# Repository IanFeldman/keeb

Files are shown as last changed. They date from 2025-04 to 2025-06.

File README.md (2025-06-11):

# A minimal ergo keyboard
Low profile, split, ortholinear, 34-key layout staggered to my natural finger rest positions. Designed for Gateron KS-33 Red swiches and DSA keycaps.
See write-up [here](https://ianfeldman.dev/projects/keyboard/).
<br><br>

Keyboard

## Features
- N-key rollover
- Efficient matrixless polling
- Lightweight and portable
- Serial communication between splits
- USB-C host connection

## Hardware Build Instructions
- Order and assemble PCB's
  - Reflow recommended for all surface mount components except SPI headers, TRRS jack, and crystal oscillator.
  - On hardware version 1.1, there are duplicate C2 and C3 traces. Only solder one C2 and one C3.
- Configure programming setup using In-system programmer (ensure shared ground)
- Power on PCB through USB-C connector
<br><br> _Note: only one PCB can be flashed at a time_

## Software Build and Flash Instructions (Linux)
```sh
# Install dependencies
sudo apt install gcc-avr avr-libc avrdude make

# Clone this repo
git clone https://github.com/IanFeldman/keeb.git
cd keeb

# Compile left or right half
make [left] [right]

# Update makefile targets 'fuses' and 'flash' as needed for your ISP device
# Set fuses with ISP (first time only)
make fuses

# Flash keyboard with ISP
make flash
```

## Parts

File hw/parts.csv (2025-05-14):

Identifier | Digikey Part Number | Unit Quantity | Total Quantity | Description
U1 | ATMEGA16U2-AU-ND | 1 | 2 | mcu
Y1 | XC1282CT-ND | 1 | 2 | 16Mhz crystal
J1 | 2073-USB4105-GF-ACT-ND | 1 | 2 | usbc connector
J2 | CP-SJ2-3574A-SMT-CT-ND | 1 | 2 | trrs connector
J3 | WM20565CT-ND | 1 | 2 | pins
SW1 | CKN12221-1-ND | 1 | 2 | push button
D1, D2, D3, D4 | 475-LSR976-NR-1CT-ND | 4 | 8 | leds
R1, R6, R7, R8, R9, R10 | RMCF0805FT10K0CT-ND | 6 | 12 | 10kohm
R2, R3 | RMCF0805JT22R0CT-ND | 2 | 4 | 22ohm
R4, R5 | RMCF0805JT5K10CT-ND | 2 | 4 | 5.1kohm
C1, C4, C5 | 311-1365-1-ND | 3 | 6 | 1uf
C2, C3 | 311-3614-1-ND | 2 | 4 | 20pf

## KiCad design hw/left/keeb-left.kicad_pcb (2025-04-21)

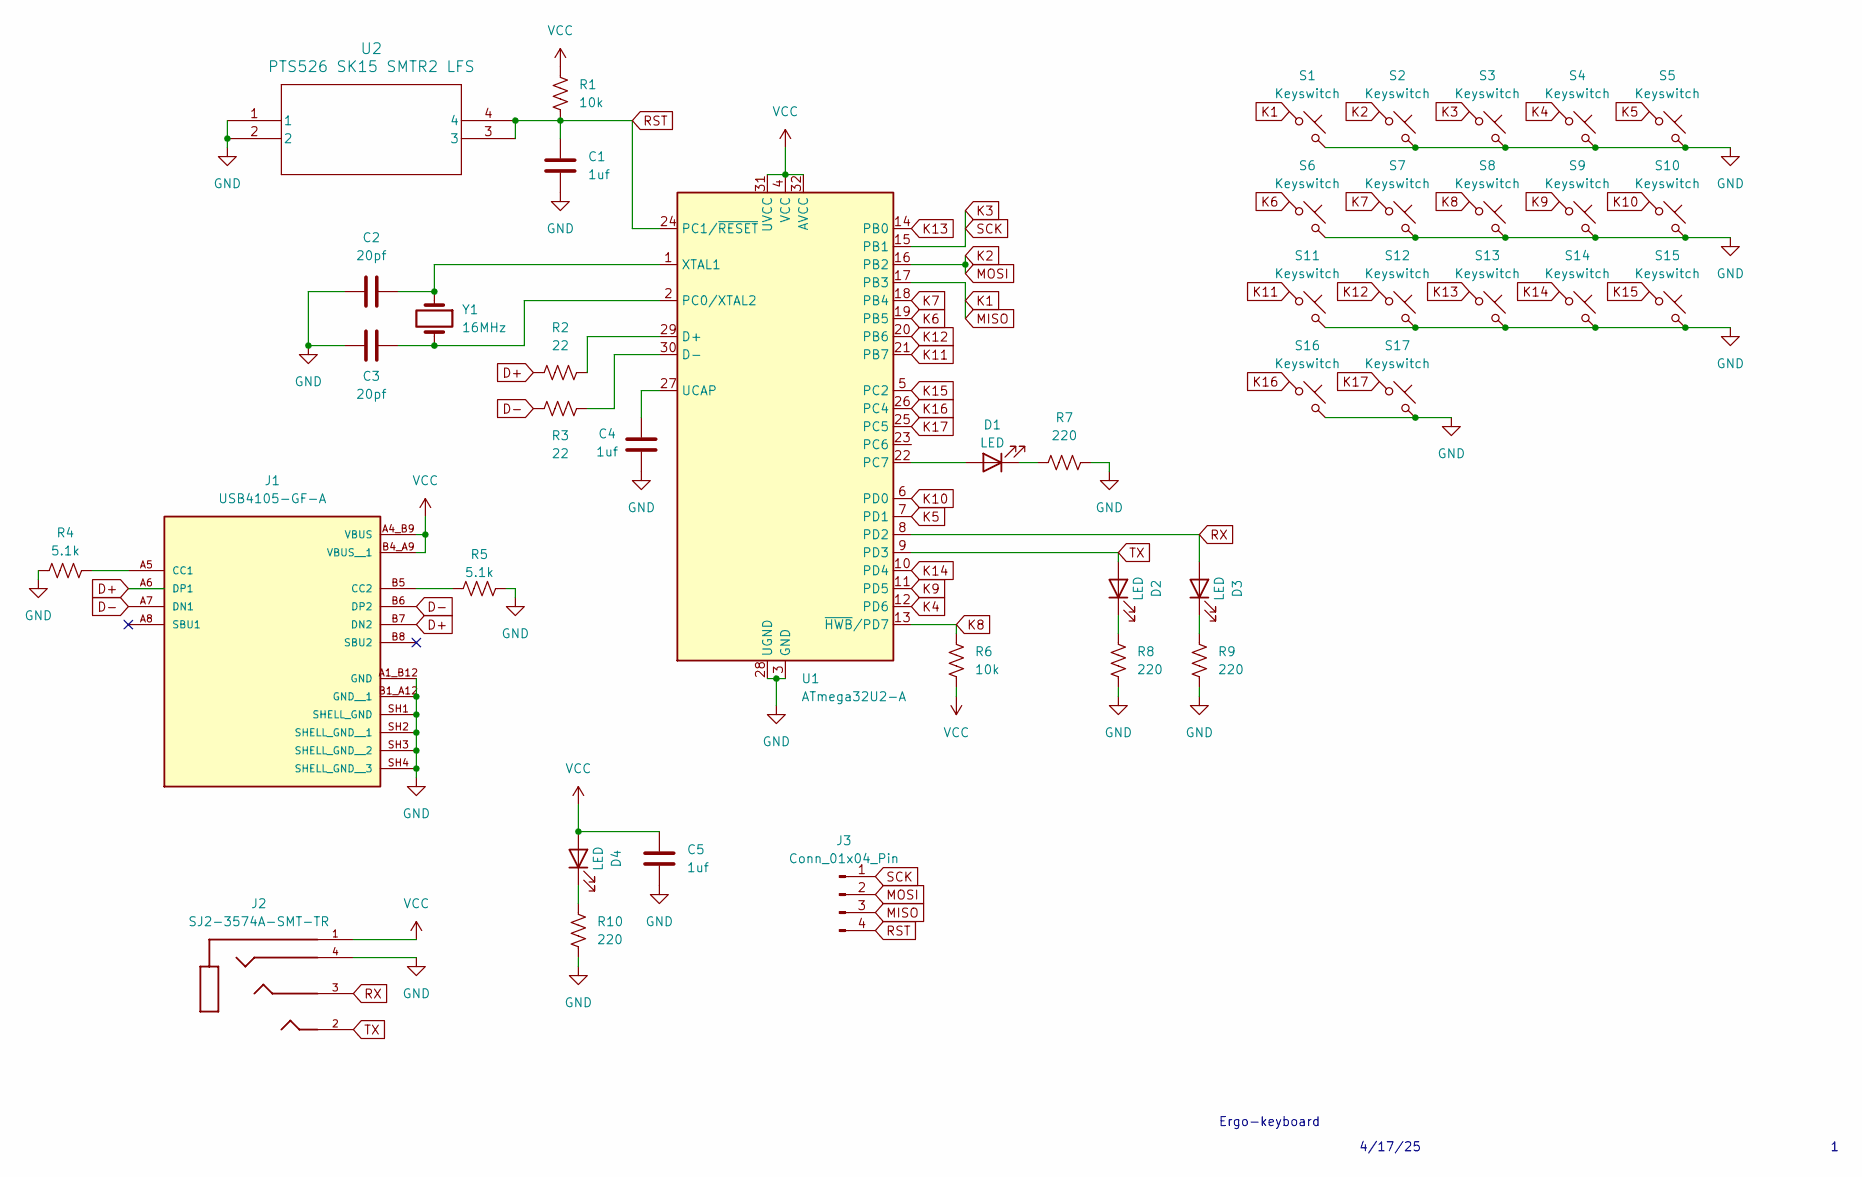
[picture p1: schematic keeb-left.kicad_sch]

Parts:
C1, C4, C5: 1uf; C_0805_2012Metric
C2, C3: 20pf; C_0805_2012Metric
D1, D2, D3, D4: LED; LED_0805_2012Metric
J1: USB4105-GF-A; GCT_USB4105-GF-A; PARTREV B4
J2: SJ2-3574A-SMT-TR; SAMESKY_SJ2-3574A-SMT-TR; PARTREV 1.05
J3: Conn_01x04_Pin; PinSocket_1x04_P2.54mm_Vertical_SMD_Pin1Right
R1, R6: 10k; R_0805_2012Metric
R2, R3: 22; R_0805_2012Metric
R4, R5: 5.1k; R_0805_2012Metric
R7, R8, R9, R10: 220; R_0805_2012Metric
S1, S2, S3, S4, S5, S6, S7, S8, S9, S10, S11, S12, S13, S14, S15, S16, S17: Keyswitch; SW_Gateron_LowProfile_THT_New
U1: ATmega32U2-A; TQFP-32_7x7mm_P0.8mm
U2: PTS526 SK15 SMTR2 LFS; SMT_FS
Y1: 16MHz; XTAL_ECS-160-20-5PX-TR

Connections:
D+: J1.A6 (DP1), J1.B7 (DN2), R2.1
D-: J1.A7 (DN1), J1.B6 (DP2), R3.1
GND: C1.2, C2.1, C3.2, C4.1, C5.1, J1.A1_B12 (GND), J1.B1_A12 (GND__1), J1.SH1 (SHELL_GND), J1.SH2 (SHELL_GND__1), J1.SH3 (SHELL_GND__2), J1.SH4 (SHELL_GND__3), J2.4, R4.1, R5.2, R7.1, R8.1, R9.1, R10.1, S1.2, S2.2, S3.2, S4.2, S5.2, S6.2, S7.2, S8.2, S9.2, S10.2, S11.2, S12.2, S13.2, S14.2, S15.2, S16.2, S17.2, U1.3 (GND), U1.28 (UGND), U2.1, U2.2
K1: J3.3, S1.1, U1.17 (PB3)
K2: J3.2, S2.1, U1.16 (PB2)
K3: J3.1, S3.1, U1.15 (PB1)
K4: S4.1, U1.12 (PD6)
K5: S5.1, U1.7 (PD1)
K6: S6.1, U1.19 (PB5)
K7: S7.1, U1.18 (PB4)
K8: R6.2, S8.1, U1.13 (~HWB/PD7)
K9: S9.1, U1.11 (PD5)
K10: S10.1, U1.6 (PD0)
K11: S11.1, U1.21 (PB7)
K12: S12.1, U1.20 (PB6)
K13: S13.1, U1.14 (PB0)
K14: S14.1, U1.10 (PD4)
K15: S15.1, U1.5 (PC2)
K16: S16.1, U1.26 (PC4)
K17: S17.1, U1.25 (PC5)
unnamed: D1.2 (A), U1.22 (PC7)
unnamed: D1.1 (K), R7.2
unnamed: D2.1 (K), R8.2
unnamed: D3.1 (K), R9.2
unnamed: D4.1 (K), R10.2
unnamed: J1.A5 (CC1), R4.2
unnamed: J1.B5 (CC2), R5.1
unnamed: R2.2, U1.29 (D+)
unnamed: R3.2, U1.30 (D-)
unnamed: C3.1, U1.2 (PC0/XTAL2), Y1.2
unnamed: C4.2, U1.27 (UCAP)
unnamed: C2.2, U1.1 (XTAL1), Y1.1
RST: C1.1, J3.4, R1.2, U1.24 (PC1/~RESET), U2.3, U2.4
RX: D3.2 (A), J2.3, U1.8 (PD2)
TX: D2.2 (A), J2.2, U1.9 (PD3)
VCC: C5.2, D4.2 (A), J1.A4_B9 (VBUS), J1.B4_A9 (VBUS__1), J2.1, R1.1, R6.1, U1.4 (VCC), U1.31 (UVCC), U1.32 (AVCC)

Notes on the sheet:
Ergo-keyboard
4/17/25

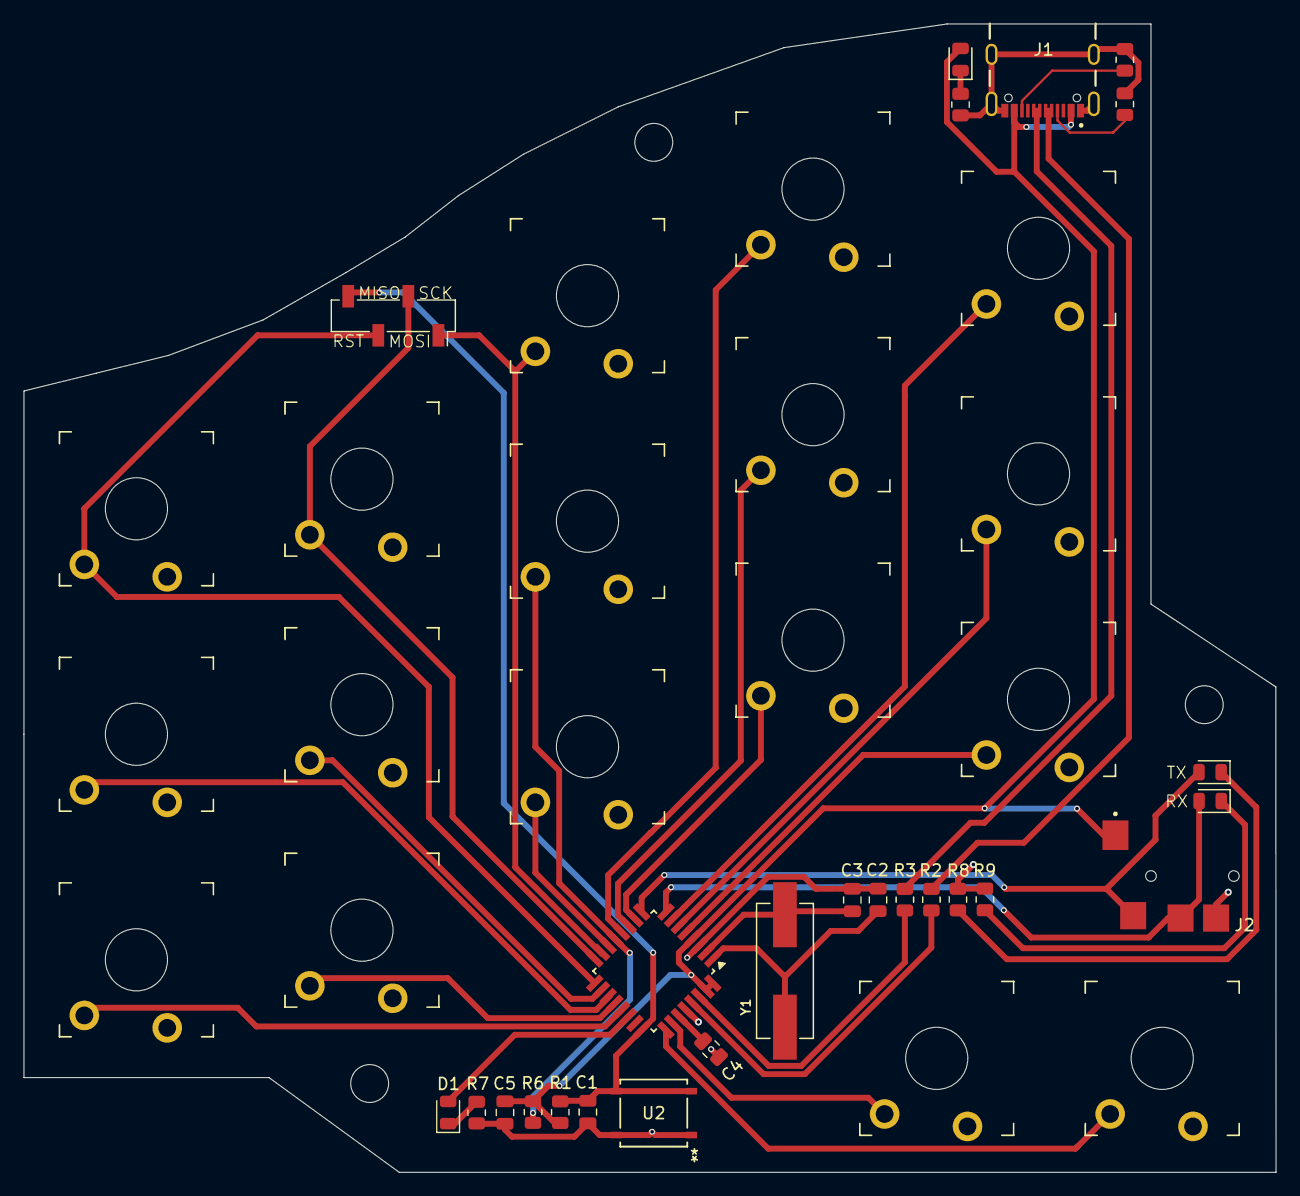
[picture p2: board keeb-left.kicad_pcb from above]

Board: 2 copper layers, 105.8 x 97.0 mm, 42 parts (0 on the bottom side), 36 nets.

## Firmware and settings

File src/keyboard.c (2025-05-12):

/*
             LUFA Library
     Copyright (C) Dean Camera, 2021.

  dean [at] fourwalledcubicle [dot] com
           www.lufa-lib.org
*/

/*
  Copyright 2021  Dean Camera (dean [at] fourwalledcubicle [dot] com)

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
  The author disclaims all warranties with regard to this
  software, including all implied warranties of merchantability
  and fitness.  In no event shall the author be liable for any
  special, indirect or consequential damages or any damages
  whatsoever resulting from loss of use, data or profits, whether
  in an action of contract, negligence or other tortious action,
  arising out of or in connection with the use or performance of
  this software.
*/

/*
 * Edited by Ian Feldman
 * April 2025
 */

#include <stdint.h>
#include "device.h"
#include "keyboard.h"
#include "nkrohid.h"
#include "uart.h"

/* report buffer to store incoming keys from peripheral */
volatile USB_NKRO_Report_Data_t report_buffer_g = {0};
/* keep track if this is main or peripheral */
volatile int main_unit_g = 0;
/* peripheral log if layer key pressed by main */
volatile int layer_key_press_g = 0;

/** Buffer to hold the previously generated Keyboard HID report, for comparison purposes inside the HID class driver. */
static uint8_t PrevKeyboardHIDReportBuffer[sizeof(USB_NKRO_Report_Data_t)];

/** LUFA HID Class driver interface configuration and state information. This structure is
 *  passed to all HID Class driver functions, so that multiple instances of the same class
 *  within a device can be differentiated from one another.
 */
USB_ClassInfo_HID_Device_t Keyboard_HID_Interface =
{
    .Config =
    {
        .InterfaceNumber = INTERFACE_ID_Keyboard,
        .ReportINEndpoint =
        {
            .Address = KEYBOARD_EPADDR,
            .Size = KEYBOARD_EPSIZE,
            .Banks = 1,
        },
        .PrevReportINBuffer = PrevKeyboardHIDReportBuffer,
        .PrevReportINBufferSize = sizeof(PrevKeyboardHIDReportBuffer),
    },
};


/** Main program entry point. This routine contains the overall program flow, including initial
 *  setup of all components and the main program loop.
 */
int main(void)
{
    SetupHardware();

    GlobalInterruptEnable();

    for (;;)
    {
        PeripheralTask();
        HID_Device_USBTask(&Keyboard_HID_Interface);
        USB_USBTask();
    }
}

/** Configures the board hardware and chip peripherals for the demo's functionality. */
void SetupHardware()
{
    /* Disable watchdog if enabled by bootloader/fuses */
    MCUSR &= ~(1 << WDRF);
    wdt_disable();

    /* Disable clock division */
    clock_prescale_set(clock_div_1);

    /* Hardware initialization */
    device_init();
    uart_init();
    USB_Init();
}

/** Peripheral main loop */
void PeripheralTask()
{
    /* skip if not peripheral */
    if (main_unit_g) return;

    /* create usb report */
    USB_NKRO_Report_Data_t KeyboardReport = {0};

    /* poll keys */
    uint8_t input = device_poll(&KeyboardReport, layer_key_press_g);

    /* send keypresses */
    if (input)
    {
        uart_send_report(&KeyboardReport);
    }
}

/** Event handler for the library USB Connection event. */
void EVENT_USB_Device_Connect(void)
{
    main_unit_g = 1;
    device_blink(2);
}

/** Event handler for the library USB Disconnection event. */
void EVENT_USB_Device_Disconnect(void)
{
    main_unit_g = 0;
    device_blink(3);
}

/** Event handler for the library USB Configuration Changed event. */
void EVENT_USB_Device_ConfigurationChanged(void)
{
    bool ConfigSuccess = true;

    ConfigSuccess &= HID_Device_ConfigureEndpoints(&Keyboard_HID_Interface);

    USB_Device_EnableSOFEvents();
}

/** Event handler for the library USB Control Request reception event. */
void EVENT_USB_Device_ControlRequest(void)
{
    HID_Device_ProcessControlRequest(&Keyboard_HID_Interface);
}

/** Event handler for the USB device Start Of Frame event. */
void EVENT_USB_Device_StartOfFrame(void)
{
    HID_Device_MillisecondElapsed(&Keyboard_HID_Interface);
}

/** HID class driver callback function for the creation of HID reports to the host.
 *
 *  \param[in]     HIDInterfaceInfo  Pointer to the HID class interface configuration structure being referenced
 *  \param[in,out] ReportID    Report ID requested by the host if non-zero, otherwise callback should set to the generated report ID
 *  \param[in]     ReportType  Type of the report to create, either HID_REPORT_ITEM_In or HID_REPORT_ITEM_Feature
 *  \param[out]    ReportData  Pointer to a buffer where the created report should be stored
 *  \param[out]    ReportSize  Number of bytes written in the report (or zero if no report is to be sent)
 *
 *  \return Boolean \c true to force the sending of the report, \c false to let the library determine if it needs to be sent
 */
bool CALLBACK_HID_Device_CreateHIDReport(USB_ClassInfo_HID_Device_t* const HIDInterfaceInfo,
    uint8_t* const ReportID,
    const uint8_t ReportType,
    void* ReportData,
    uint16_t* const ReportSize)
{
    /* skip if peripheral */
    if (!main_unit_g) return false;

    /* create usb report */
    USB_NKRO_Report_Data_t* KeyboardReport = (USB_NKRO_Report_Data_t*)ReportData;

    /* poll keys */
    /* get buffered keys first because it might contain layer info */
    memcpy(KeyboardReport, (uint8_t *)&report_buffer_g, sizeof(USB_NKRO_Report_Data_t));
    /* clear buffer */
    memset((uint8_t *)&report_buffer_g, 0x00, sizeof(USB_NKRO_Report_Data_t));

    /* poll main device */
    device_poll(KeyboardReport, layer_key_press_g);
    layer_key_press_g = 0;

    /* send layer key */
    uart_send_layer_info(KeyboardReport);

    /* subtract one for layer byte */
    *ReportSize = sizeof(USB_NKRO_Report_Data_t) - 1;
    return false;
}

/** HID class driver callback function for the processing of HID reports from the host.
 *
 *  \param[in] HIDInterfaceInfo  Pointer to the HID class interface configuration structure being referenced
 *  \param[in] ReportID    Report ID of the received report from the host
 *  \param[in] ReportType  The type of report that the host has sent, either HID_REPORT_ITEM_Out or HID_REPORT_ITEM_Feature
 *  \param[in] ReportData  Pointer to a buffer where the received report has been stored
 *  \param[in] ReportSize  Size in bytes of the received HID report
 */
void CALLBACK_HID_Device_ProcessHIDReport(USB_ClassInfo_HID_Device_t* const HIDInterfaceInfo,
    const uint8_t ReportID,
    const uint8_t ReportType,
    const void* ReportData,
    const uint16_t ReportSize)
{
    /* skip if peripheral */
    if (!main_unit_g) return;
}

/* Main unit receive key state and save to global report buffer
 * Peripheral receive single byte indicating layer key press */
ISR(USART1_RX_vect)
{
    static interrupt_st state = AWAIT_REPORT;
    static int key_idx = 0;

    /* get data */
    uint8_t data = UDR1;

    /* if peripheral, first rx indicates layer key status */
    if (!main_unit_g)
    {
        layer_key_press_g = !!data;
        return;
    }

    /* if main */
    switch(state)
    {
        case AWAIT_REPORT:
            if (data == FRAME_START)
            {
                state = READ_MODIFIER;
            }
            break;
        case READ_MODIFIER:
            report_buffer_g.Modifier |= data;
            state = READ_KEYS;
            break;
        case READ_KEYS:
            report_buffer_g.Keys[key_idx++] |= data;
            if (key_idx >= KEY_BUFFER_SIZE)
            {
                state = READ_LAYER;
                key_idx = 0;
            }
            break;
        case READ_LAYER:
            layer_key_press_g = !!data;
            state = AWAIT_REPORT;
            break;
        default:
            break;
    }
}

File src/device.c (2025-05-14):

#include <avr/io.h>
#include <LUFA/Drivers/USB/USB.h>
#include <util/delay.h>
#include "device.h"
#include "nkrohid.h"

/* Initialize device hardware */
void device_init(void)
{
    /* insert delay to avoid pull up contention  */
    _delay_ms(500);

    /* configure ports as inputs */
    DDRB = 0x00;
    DDRC = 0x00;
    DDRD = 0x00;

    /* enable pull up resistors */
    PORTB = 0xFF;
    PORTC = 0xFF;
    PORTD = 0xFF;

    /* debug led */
    DDRC |= (1 << DEBUG_LED);
    PORTC &= ~(1 << DEBUG_LED);
}


/* Blink debug led */
void device_blink(int count)
{
    for (int i = 0; i < count; i++)
    {
        PORTC ^= (1 << DEBUG_LED);
        _delay_ms(50);
        PORTC ^= (1 << DEBUG_LED);
        _delay_ms(50);
    }
}


/* Enable debug led */
void device_enable_led(int on)
{
    PORTC = on ? (PORTC | (1 << DEBUG_LED)) : (PORTC & ~(1 << DEBUG_LED));
}


/* Poll for keypresses, save to key report.
 * Extern_layer_key is input high when the other unit's layer key is pressed.
 * Return a value if any keys are pressed, 0 otherwise. */
uint8_t device_poll(USB_NKRO_Report_Data_t *report, uint8_t extern_layer_key)
{
    /* used for edge case when layer key lifted and keys still depressed */
    static uint8_t layer_hold = 0;
    static uint8_t prev_layer = 0;
    static uint8_t prev_port_b = 0;
    static uint8_t prev_port_c = 0;
    static uint8_t prev_port_d = 0;

    /* read ports */
    uint8_t port_b = PINB;
    uint8_t port_c = PINC | ~PORTC_INPUT;
    uint8_t port_d = PIND | ~PORTD_INPUT;
    uint8_t input = ~(port_b & port_c & port_d);
    uint8_t input_static = (port_b == prev_port_b) &&
                           (port_c == prev_port_c) &&
                           (port_d == prev_port_d);
    uint8_t input_static_sans_layer = (port_b == prev_port_b) &&
                                      ((port_c & ~LAYER_POS) == (prev_port_c & ~LAYER_POS)) &&
                                      (port_d == prev_port_d);

    /* clear layer hold when any input changes */
    layer_hold &= input_static;
    /* check if layer key pressed */
    report->Layer |= !(port_c & LAYER_POS);
    uint8_t layer_active = report->Layer || extern_layer_key || layer_hold;
    /* set layer hold */
    layer_hold |= !layer_active && prev_layer && input_static_sans_layer;
    /* re-evaluate layer_active */
    layer_active = report->Layer || extern_layer_key || layer_hold;

    #ifdef LEFT
    if (!layer_active)
    {
        /* port b */
        report->Keys[SC_TO_IDX(HID_KEYBOARD_SC_X)] |= SC_TO_MSK(HID_KEYBOARD_SC_X) * !(port_b & (1 << 0));
        report->Keys[SC_TO_IDX(HID_KEYBOARD_SC_W)] |= SC_TO_MSK(HID_KEYBOARD_SC_W) * !(port_b & (1 << 1));
        report->Keys[SC_TO_IDX(HID_KEYBOARD_SC_Q)] |= SC_TO_MSK(HID_KEYBOARD_SC_Q) * !(port_b & (1 << 2));
        report->Keys[SC_TO_IDX(HID_KEYBOARD_SC_ESCAPE)] |=
            SC_TO_MSK(HID_KEYBOARD_SC_ESCAPE) * !(port_b & (1 << 3));
        report->Keys[SC_TO_IDX(HID_KEYBOARD_SC_A)] |= SC_TO_MSK(HID_KEYBOARD_SC_A) * !(port_b & (1 << 4));
        report->Keys[SC_TO_IDX(HID_KEYBOARD_SC_TAB)] |=
            SC_TO_MSK(HID_KEYBOARD_SC_TAB) * !(port_b & (1 << 5));
        report->Modifier |= HID_KEYBOARD_MODIFIER_LEFTCTRL * !(port_b & (1 << 6));
        report->Modifier |= HID_KEYBOARD_MODIFIER_LEFTSHIFT * !(port_b & (1 << 7));
        /* port c */
        report->Keys[SC_TO_IDX(HID_KEYBOARD_SC_V)] |= SC_TO_MSK(HID_KEYBOARD_SC_V) * !(port_c & (1 << 2));
        report->Keys[SC_TO_IDX(HID_KEYBOARD_SC_SPACE)] |=
            SC_TO_MSK(HID_KEYBOARD_SC_SPACE) * !(port_c & (1 << 5));
        /* port d */
        report->Keys[SC_TO_IDX(HID_KEYBOARD_SC_F)] |= SC_TO_MSK(HID_KEYBOARD_SC_F) * !(port_d & (1 << 0));
        report->Keys[SC_TO_IDX(HID_KEYBOARD_SC_R)] |= SC_TO_MSK(HID_KEYBOARD_SC_R) * !(port_d & (1 << 1));
        report->Keys[SC_TO_IDX(HID_KEYBOARD_SC_C)] |= SC_TO_MSK(HID_KEYBOARD_SC_C) * !(port_d & (1 << 4));
        report->Keys[SC_TO_IDX(HID_KEYBOARD_SC_D)] |= SC_TO_MSK(HID_KEYBOARD_SC_D) * !(port_d & (1 << 5));
        report->Keys[SC_TO_IDX(HID_KEYBOARD_SC_E)] |= SC_TO_MSK(HID_KEYBOARD_SC_E) * !(port_d & (1 << 6));
        report->Keys[SC_TO_IDX(HID_KEYBOARD_SC_S)] |= SC_TO_MSK(HID_KEYBOARD_SC_S) * !(port_d & (1 << 7));
    }
    else
    {
        /* port b */
        report->Keys[SC_TO_IDX(HID_KEYBOARD_SC_Z)] |= SC_TO_MSK(HID_KEYBOARD_SC_Z) * !(port_b & (1 << 0));
        report->Keys[SC_TO_IDX(HID_KEYBOARD_SC_3_AND_HASHMARK)] |=
            SC_TO_MSK(HID_KEYBOARD_SC_3_AND_HASHMARK) * !(port_b & (1 << 1));
        report->Keys[SC_TO_IDX(HID_KEYBOARD_SC_2_AND_AT)] |=
            SC_TO_MSK(HID_KEYBOARD_SC_2_AND_AT) * !(port_b & (1 << 2));
        report->Keys[SC_TO_IDX(HID_KEYBOARD_SC_1_AND_EXCLAMATION)] |=
            SC_TO_MSK(HID_KEYBOARD_SC_1_AND_EXCLAMATION) * !(port_b & (1 << 3));
        report->Keys[SC_TO_IDX(HID_KEYBOARD_SC_BACKSLASH_AND_PIPE)] |=
            SC_TO_MSK(HID_KEYBOARD_SC_BACKSLASH_AND_PIPE) * !(port_b & (1 << 4));
        report->Keys[SC_TO_IDX(HID_KEYBOARD_SC_GRAVE_ACCENT_AND_TILDE)] |=
            SC_TO_MSK(HID_KEYBOARD_SC_GRAVE_ACCENT_AND_TILDE) * !(port_b & (1 << 5));
        report->Modifier |= HID_KEYBOARD_MODIFIER_LEFTCTRL * !(port_b & (1 << 6));
        report->Modifier |= HID_KEYBOARD_MODIFIER_LEFTSHIFT * !(port_b & (1 << 7));
        /* port c */
        report->Keys[SC_TO_IDX(HID_KEYBOARD_SC_B)] |= SC_TO_MSK(HID_KEYBOARD_SC_B) * !(port_c & (1 << 2));
        report->Keys[SC_TO_IDX(HID_KEYBOARD_SC_SPACE)] |=
            SC_TO_MSK(HID_KEYBOARD_SC_SPACE) * !(port_c & (1 << 5));
        /* port d */
        report->Keys[SC_TO_IDX(HID_KEYBOARD_SC_G)] |= SC_TO_MSK(HID_KEYBOARD_SC_G) * !(port_d & (1 << 0));
        report->Keys[SC_TO_IDX(HID_KEYBOARD_SC_T)] |= SC_TO_MSK(HID_KEYBOARD_SC_T) * !(port_d & (1 << 1));
        report->Modifier |= HID_KEYBOARD_MODIFIER_LEFTALT * !(port_d & (1 << 4));
        report->Keys[SC_TO_IDX(HID_KEYBOARD_SC_CLOSING_BRACKET_AND_CLOSING_BRACE)] |=
            SC_TO_MSK(HID_KEYBOARD_SC_CLOSING_BRACKET_AND_CLOSING_BRACE) * !(port_d & (1 << 5));
        report->Keys[SC_TO_IDX(HID_KEYBOARD_SC_4_AND_DOLLAR)] |=
            SC_TO_MSK(HID_KEYBOARD_SC_4_AND_DOLLAR) * !(port_d & (1 << 6));
        report->Keys[SC_TO_IDX(HID_KEYBOARD_SC_OPENING_BRACKET_AND_OPENING_BRACE)] |=
            SC_TO_MSK(HID_KEYBOARD_SC_OPENING_BRACKET_AND_OPENING_BRACE) * !(port_d & (1 << 7));
    }
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

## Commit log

2025-04-19 Add hw files
    [keeb.kicad_pcb, keeb.kicad_sch]
2025-04-19 Add right board
    [keeb-left.kicad_pcb, keeb-left.kicad_sch, keeb-right.kicad_pcb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]
2025-04-19 Remove original
    [keeb.kicad_pcb, keeb.kicad_sch]
2025-04-21 Hardware revision
    [keeb-left.kicad_pcb, keeb-right.kicad_pcb, keeb-right.kicad_sch]
2025-04-29 Fix avrdude cmds, add debug flash
    [keyboard.c]
2025-04-30 Add uart
2025-04-30 Add device
2025-04-30 Fix report send logic
    [device.c, keyboard.c, uart.c]
2025-05-01 Reset key buffer and update interrupt handling
    [uart.c]
2025-05-01 Increase uart speed
2025-05-01 Report over uart works!
2025-05-03 Fix layer breaking bug
    [device.c, keyboard.c]
2025-05-06 Pass in references to uart functions
2025-05-12 Enable led on layer press
2025-05-14 Update hardware
    [keeb-left.kicad_sch, keeb-right.kicad_sch, parts.csv]
2025-05-14 Fix parts list
    [parts.csv]
